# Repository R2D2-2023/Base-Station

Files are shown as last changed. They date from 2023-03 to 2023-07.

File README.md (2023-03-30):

# Base-Station

We are the team base-station.

> Our focus is on the charging of the robot and also maintaining the robot, by charging it and maybe updating it in times.
>  - Charging will be done with a contact pad and an arm that moves these pads to connect to the robot.
>  - Updating will be done by the same action, the pads all have a different function
>        The functions are;
>      - Charging, by using a ground and power pad.
>      - Data transfer.
>      - Powering on the Raspberry Pi for data transfers.

To see the [scrumboard](https://github.com/orgs/R2D2-2023/projects/4) of our team

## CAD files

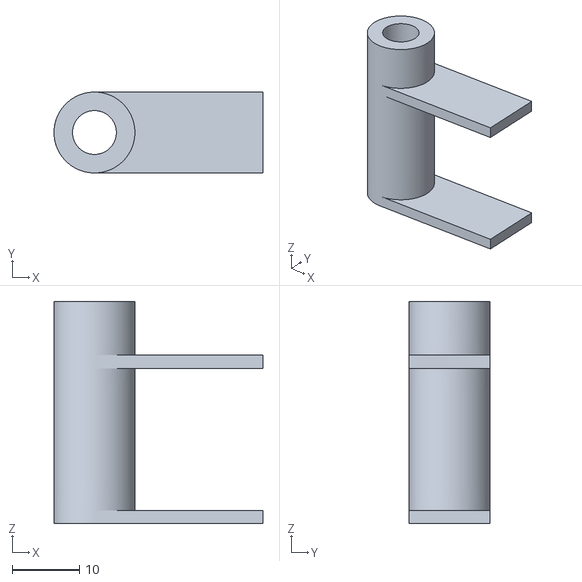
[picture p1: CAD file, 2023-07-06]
models/3d_models/LaserHouder.stl
31.0 x 12.0 x 33.0

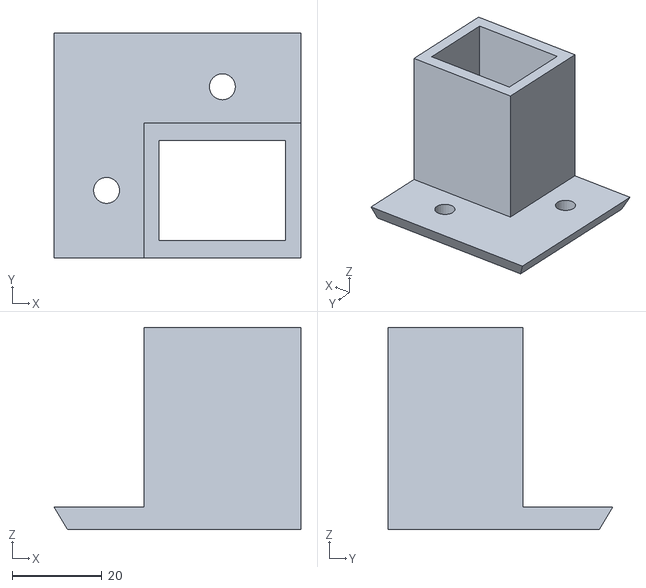
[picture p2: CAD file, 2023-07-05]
models/3d_models/holder_switch.stl
55.0 x 50.0 x 45.0

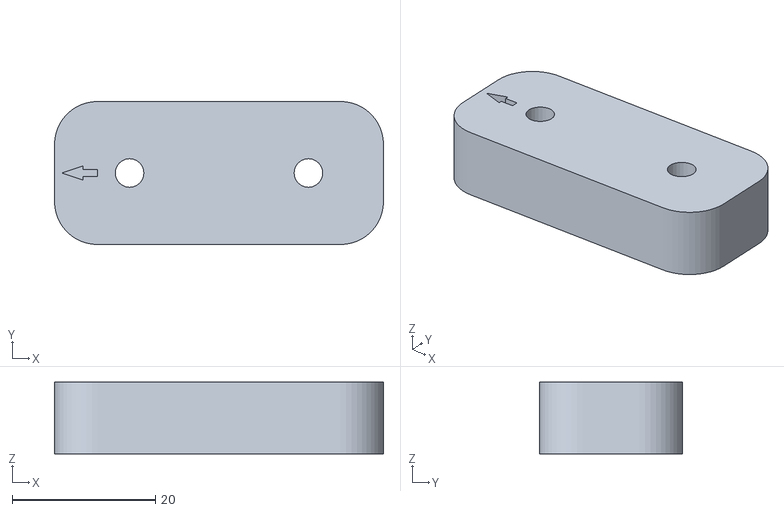
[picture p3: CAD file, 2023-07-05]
models/3d_models/connector_longside.stl
46.0 x 20.0 x 10.0

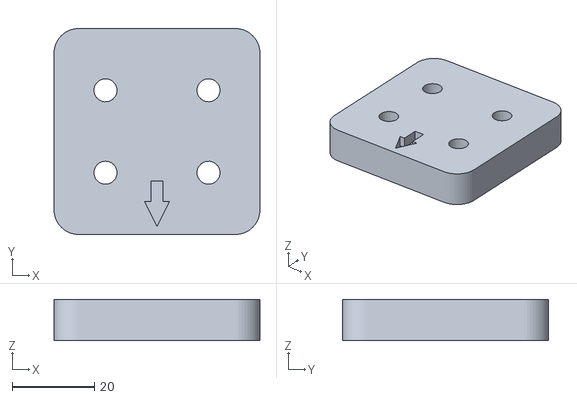
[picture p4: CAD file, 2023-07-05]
models/3d_models/middle_connector (1).stl
50.0 x 50.0 x 10.0

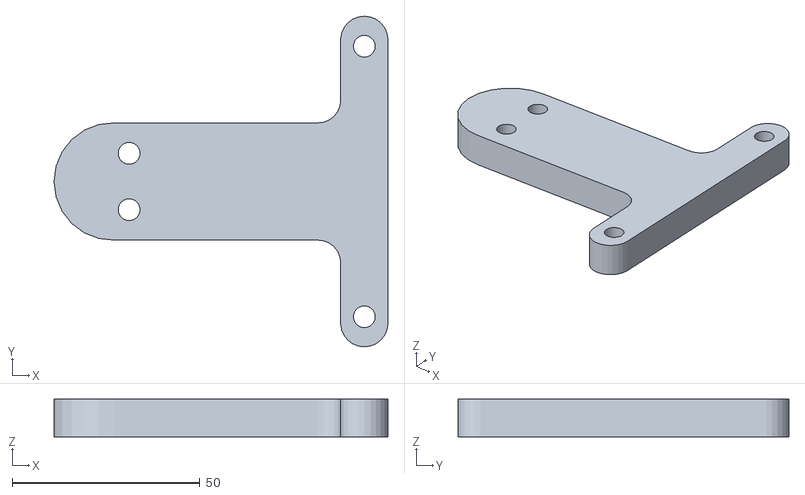
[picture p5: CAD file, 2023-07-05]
models/3d_models/T-connector (3).stl
88.9 x 88.0 x 10.0

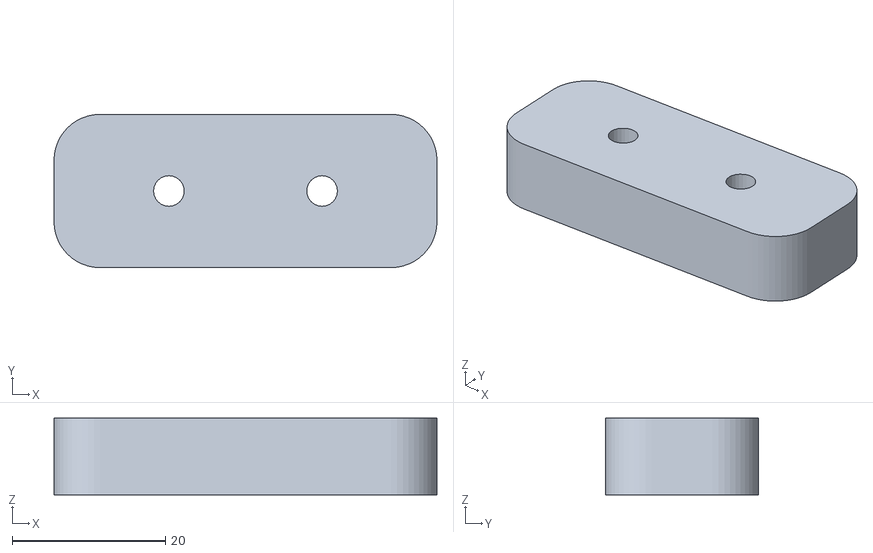
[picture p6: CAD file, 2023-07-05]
models/3d_models/connector_shortside (1).stl
50.0 x 20.0 x 10.0

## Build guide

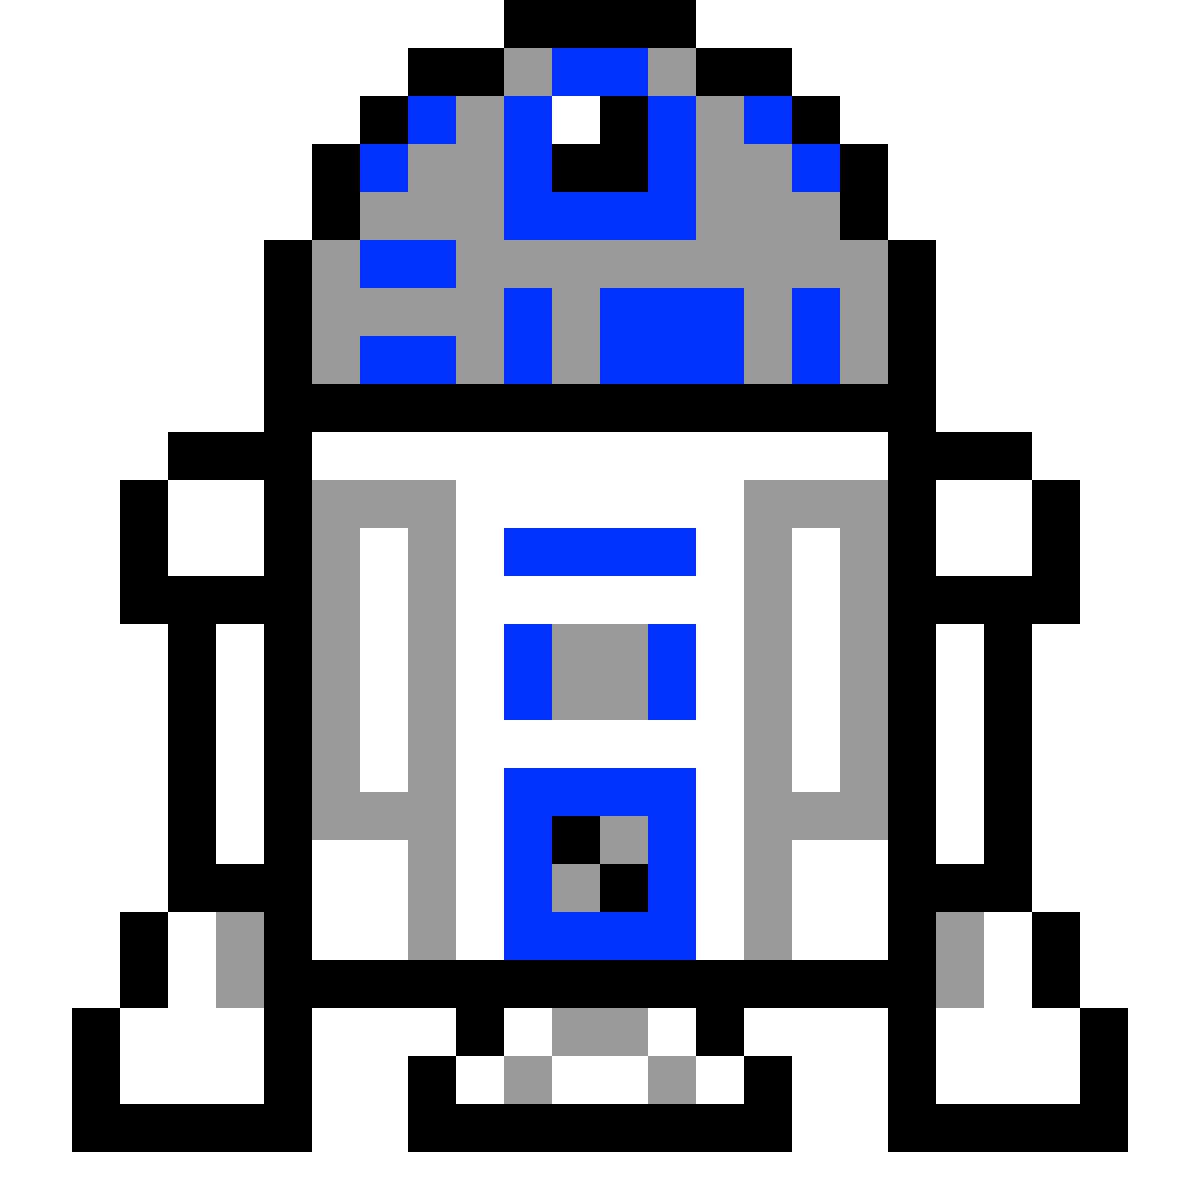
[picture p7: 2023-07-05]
Visualisation_software/cmake-build-debug-mingw/image.png

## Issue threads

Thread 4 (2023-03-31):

Loodcel op platform zetten

funrester1423, 2023-03-31:

funrester1423, 2023-04-11:
This sprint we built the mechanism out of wood and not of Lego parts, so overall it is sturdier than the original model.

We also decided to include additional beams for support, last sprint the single support beam was bent because of the weight of the pressure sensor.

funrester1423, 2023-06-12:
Done, mechanism is operational and attached to the project.

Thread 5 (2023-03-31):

Make platform for connective pads and pressure plate

funrester1423, 2023-03-31:
This is a part of the demo model.
- Making a prototype of the platform where we can place the pads and plate.

funrester1423, 2023-04-03:
Eventually the platform was made and functional, but it was not used in the prototype because the overall build was not strong enough for the weight of the pressure sensor (pressure plate) so we forwent attaching it to the first model.

funrester1423, 2023-04-11:
This has been pushed back to the previous and current sprint.

There were some changes in the build/materials also overall dimensions because of compromises with the other teams.
With the new model it should be stable compared to the older versions, we added more support beams to keep the platform more stable than it was.

funrester1423, 2023-06-12:
Issue has been moved to issue "Project".
All equivalent issues will be moved there.

Closed 2023-06-12.

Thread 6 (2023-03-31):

3D model

funrester1423, 2023-03-31:
- Making a model for the arm in SketchUp.
* This will be used to make a prototype of the arm.

funrester1423, 2023-06-12:
Issue has been moved to issue "Project".
All equivalent issues will be moved there.

Closed 2023-06-12.

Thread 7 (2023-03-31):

Apply Hall sensor

funrester1423, 2023-03-31:
Check if the arm doesn't apply too much pressure on the robot, to prevent our mechanism to break it.

funrester1423, 2023-04-03:
Functionality was fine last sprint, but it still has to be attached and we don't have the model that can support the weight of the platform.
This sprint we have to improve the existing design to make a more refined version of the arm.

funrester1423, 2023-04-11:
This sprint we have a more stable arm, with better materials and overall a better build. We added extra support for the top part of the mechanism, so the platform would stay secure and fixed to the mechanism, without it bending the mechanism to the heavier side.

This would've been a non-issue if the platform only had to hold the hallsensors and not the pressure block as well.

funrester1423, 2023-06-12:
Issue has been moved to issue "Project".
All equivalent issues will be moved there too.

Closed 2023-06-12.

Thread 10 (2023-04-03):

Demo arm

funrester1423, 2023-04-03:
Put the things from proof of concept into a working demo, to be shown to the other teams.

- An arm mechanism, that can extend itself when robot is in proximity.
- The sensors to know proximity of the robot.

funrester1423, 2023-04-03:
In the proof of concept we also had the pressure pads, these were not yet implemented in the full demo.
The pad itself was too heavy to be used with the current model, where the overall base of it is just too weak for a weight that would extend itself away from the base.
Though it is functional, it just could not be applied to the mechanism.

Closed 2023-04-03.

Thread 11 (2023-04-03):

Batterij research

funrester1423, 2023-04-03:
- Which battery will be used.
- How to charge said battery.
- How can we charge it safely.
- Estimation how long it would take to charge the battery.

funrester1423, 2023-04-04:
B-25C-3300-3S1P = The battery that will be used
- Charging methods that we could think of are.
- - Using a power outlet
- - Using a USB connection
- - Using coils
- - Using metal pads to replace cables.

funrester1423, 2023-06-05:
Only the coils have to be checked, but the other 3 methods have been tested.
- Overall the charging took a while.
- There isn't a very noticable difference in charging speed for all of them, which is probably based on the power that we can deliver.

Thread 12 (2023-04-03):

Parts list

funrester1423, 2023-04-03:
Parts needed for the mechanism

- 3144E Holzer hall sensor
- HX711 load cell 1kg
- 5V DC gear motor (unnamed/general)
- L9110S H-Bridge
- Wooden parts for mechanism and for ramp
- Wooden parts for the platform

funrester1423, 2023-06-05:
Ramp was removed because of clashes with the mobile platforms model, it can't go up ramps.

Added items to the list for testing charge speeds:
- Coils
- Pads

funrester1423, 2023-06-12:
All parts and additional parts have been acquired.

Closed 2023-06-12.

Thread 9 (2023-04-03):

Demo model v2

funrester1423, 2023-04-03:
Making a second model, which is meant to be an improvement to our model from the previous sprint.
Focusing on making a more stable model, that would be able to carry their parts.

- Same parts as before, but increasing the durabilty of the material or improving the design, for stability.

funrester1423, 2023-06-12:
Issue has been moved to issue "Project".
All equivalent issues will be moved there.

Closed 2023-06-12.

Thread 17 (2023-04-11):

Battery management

funrester1423, 2023-04-11:
Making a system to check if the battery is full.

This might be a good addition predominantly for safety and longevity of the battery.
At least we should be able to know when the battery is full and not overload the battery.

funrester1423, 2023-06-12:
New plan:
- We will be making a display in the base station to display the battery level of the robot, this will be done in tandem with the backend, where they have the current battery reading of the robot during it's run.

funrester1423, 2023-06-26:
We only need access to the backend for their collection of data, so we could take the battery levels, that they should be getting from the robot as well.

funrester1423, 2023-06-27:
The battery management will be done with an animation of how full the battery is at the front of the charging station.
But we heard that the mobiel platform are going to add an additional battery to their robot so at least it would have enough power to run every hardware and actually move faster than a couple meters per second.

funrester1423, 2023-06-30:
The status will be sent by MQTT, which would provide connections between the two raspberry pi's, one that can read the battery levels and the other pi will be used to control the LED-matrix

Closed 2023-07-07.

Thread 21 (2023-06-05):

Research

funrester1423, 2023-06-05:
- Prep charging methods (Kyrill)
- Weighing down wires (Erik)
- Check safety and efficiency (Jasper + Kalil)
   - Start the research (All)
   - Proces results (All)

funrester1423, 2023-06-12:
Coils definitely will not be the choice that we will be going with, because of it's severe inefficiency.
Comparatively to the other options, the coils charges way too slow to be functional.

funrester1423, 2023-06-19:
Research paper has been finished and submitted.

- For the week; a presentation has to be made.

Closed 2023-06-20.

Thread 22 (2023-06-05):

Project (Charging station)

funrester1423, 2023-06-05:
For the project, basically for the product we still have to do the following things:

- Build frame for the docking station.
- Finish electronics for the docking station.
- The pad model must revised, because of the new model of the product.
- Looking for LED matrix and testing it.
- Connection with the database from backend.

funrester1423, 2023-06-27:
Most of parts are working independently, just needs to fix some small bugs with sensors.

- The extracurricular thing was revised from last weeks product, which we already coded, but apparently the library does not support the configuration that we had made.

funrester1423, 2023-07-03:
Extracurricular items are now finished, we only have a slight drawback, the raspberry Pi that controls the pads was corrupted, so we have to remake the Pi, which shouldn't take too long and would be done for tomorrow, so we can have a final check if everything works and error free, to the extent that it is functional enough to do what we need it to do.

The sensors are all working as intended, we have to just place the plate and also reinstall the second Pi.

funrester1423, 2023-07-07:
Finished the product, has a bit of a delay till startup, but for the most part is fully functional, might have some test cases where it doesn't, but we couldn't get to that before the deadline of the project.

Closed 2023-07-07.

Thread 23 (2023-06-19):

Mainframe

funrester1423, 2023-06-19:
Piecing together the charging box:

- Frame of the box
- Completing mechanism.

funrester1423, 2023-06-26:
Frame might need some reinforcements, to keep the lasers on their position.

funrester1423, 2023-06-27:
The motor is slowly but surely wrecking our frame, the overall pressure caused by the 2 motors is too high for the thin wooden frame we made for the mechanism, at least the overall box, where the mechanism will be situated, has a much stronger and thicker frame than the mechanism.

funrester1423, 2023-06-30:
Added small art to replace the empty space left from the planned panel on the top and to block the mess on the top.

funrester1423, 2023-07-03:
We did our utmost to make it into a presentable frame, but in my honest opinion in needs some work, but getting it to look better than what we have right now would need more time to hide some wiring monstrosities.

Hopefully none of thge wires would be moved till the show and tell, but once one of the wires are not in their position it might not work, we will make a picture of how it should look like and how things are connected.

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

Closed 2023-07-07.

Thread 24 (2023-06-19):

Visualisation software

funrester1423, 2023-06-19:
Controlling the LED-matrix for the dashboard and also a dedicated LED-matrix for pixel art.

- Pixel art is optional to be fully functional, so if it's not working perfectly, this shouldn't matter.
- Dashboard function should be for battery information, info that can be pulled from back-end.

funrester1423, 2023-07-03:
The Visualisation software has been made and are both functional, they are being controlled by a seperate Pi, because the connectors for the LED-matrixes take up all the GPIO pins.

A problem surfaced today (3/7), where the Raspberry Pi that controls the matrixes got corrupted, so Daniel was sent out to flash and reinstall the OS, this took a while, which where we found out that the problem is not the Pi, so that stay, but the SD-card that we were using, just suddenly gave up, so that has been changed and now only makefiles have to be remade for the new SD-card.

Closed 2023-06-20.

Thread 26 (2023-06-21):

Combine all parts

funrester1423, 2023-06-21:
Minecrafting, building block

funrester1423, 2023-06-27:
Parts are for the most part functional again, for this week (26/6) only the LED-matrix had to revised again before implementing into the charging station. Might need to think of a better fix for the stability of the lasers, but as long as the charging station frame doesn't move a signifcant amount, it should be fine.

funrester1423, 2023-07-03:
All parts are now functional and have been tested, the thing that we have to finish is just to add MQTT to the raspberries, this should allow us to send small data, in our case a string, to the other Pi.

Closed 2023-07-07.

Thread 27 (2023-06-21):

Sensors

funrester1423, 2023-06-21:
Tune sensors to where it has to be.

funrester1423, 2023-06-26:
Lasers have been set up, but might need to do something about the janky solution that we have right now, might not.

funrester1423, 2023-06-27:
- Leadcels weren't functioning properly, found out it was in the wrong ports, so that was fixed fast enough.
- Lasers are now aimed properly, but as long as the charging station frame moves too much, it might move the laser away from the receiver.
- Halsensors should be working properly, it at least shows when it is being activated, only the software needs an update, because the function of the sensors have been changed slightly.

funrester1423, 2023-07-03:
We had a couple problems with the sensors after turning the mechanism on today, this bug has been fixed by Erik and Kalil.

Closed 2023-06-30.

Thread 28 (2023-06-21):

Connection with back-end

funrester1423, 2023-06-21:
Get data for the dashboard, this includes voltage, possibly also the current position of the robot.

funrester1423, 2023-06-30:
The dashboard has been removed from our project, this has been replaced by just the battery level indicator.

Closed 2023-07-03.

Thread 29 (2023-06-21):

LED-Matrix Dashboard

funrester1423, 2023-06-21:
Dashboard specific panels / code.

funrester1423, 2023-06-27:
LED-matrix doesn't work as intended, so one of the matrix sets will have to be removed and exchanged with a different matrix.

- The original setup of one set of matrixes; 32x48 and 32x32, did not work as intended, the pixels aren't being adressed properly because of the specific configuration that we are running, the library only support a configuration with either same pixel height or width, but can't address this current config.
- The fix to this is to to remove the 32x32 setup and just swap it with an extra 16x32, which should work.

funrester1423, 2023-06-29:
Doing some final debugging, but it should be functional by today.

funrester1423, 2023-06-30:
Dashboard has been removed from the project, has been replaced by a battery indicator, the panel had to be shrunk to a single 16x32 panel, so a Dashboard doesn't seem possible to show on such a small panel.

- Battery level indicator has been finished, just needs to be connected to the battery reader on the robot, back-end or mobiel-platform.

funrester1423, 2023-07-03:
There was a problem with the Raspberry Pi that we had, after a couple hours of flashing SD-cards and re-installing Raspberian later we found out it was a problem with the SD-card and not the Pi.

This was done by Daniel and David for the most part. It took a while, but we finally found the problem and it is now fixed.

Only right now we are left with the problem of rebuilding the flashed drive of the Pi.
Things like makefiles and the clone of the repositories.

Closed 2023-07-07.

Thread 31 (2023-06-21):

Get parts to finish the box

funrester1423, 2023-06-21:
Have to get parts to finish the box, primarily new wooden boards, that will be used to close the box and extra plates for maybe mistakes and also for the robot and our charging pads.

funrester1423, 2023-06-27:
The wooden boards have been acquired together with the copper tape, so all the materials should be in inventory, if there are more purchases needed that will be added later and the issue will be reopened.

Closed 2023-06-27.

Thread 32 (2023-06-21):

Print parts for the panels

funrester1423, 2023-06-21:
3D print parts necessary to connect panels to each other.

funrester1423, 2023-06-22:
Position of holes for the parts are not symmetrical to each panel, so position of the panels have impact to the the form of the parts, so now we are making new parts that corresponds with the panel positioning.

funrester1423, 2023-06-27:
3D printed parts have been finished and added to the the mechanism, this issue should be done, unless we have to make final revisions for stability, which we think would be very unlikely.

funrester1423, 2023-07-03:
All parts should be finished, there should be no more additions for the last 2 days, because this wouldn't be doable in less that 2 days time.

Closed 2023-06-27.

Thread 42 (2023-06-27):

Charging panels

funrester1423, 2023-06-27:
The panels are made of wood and the pads will be swapped  out for copper tape, instead of aluminium pads, that's because copper is a way better conductor, also a tape is easier to apply than cutting the pads then pasting them on the pads.

funrester1423, 2023-06-27:
The original plan last week was to make two of these plates; one for base-station and one for mobiel-platform

* This was changed slightly, because the division of space on the mobiel-platform was changed, because of changes in hardware.
 - So we have to make new cut outs and also do the platings again.
 - The comment above is an extention of this comment, which missed the additional information that the original idea was already made, but after hearing that a new one had to be made, we thought of things to improve it, including using copper tape instead of aluminium pads.

funrester1423, 2023-06-27:
We have printed the secondary plate needed for mobiel platform, we only need to apply the copper tape to it, then we have to test if it fit and check how they are going to do the connectors for the 2 batterycells that they are going to use.

- The mobiel platform has to check how to connect the two battery, parallel or in sequence, dependant on how they want to do the connection we have to change how we charge the robot.

funrester1423, 2023-06-29:
Both plates are finished, only need to be added to the mechanism and to the mobiel platform.

funrester1423, 2023-07-03:
The cables only need to be soldered together and connected to the mainframe.
- We still have to discuss how we are going to arrange the pads, but the mobiel platform still needs to finish their robot, this might not happen.

Closed 2023-06-29.

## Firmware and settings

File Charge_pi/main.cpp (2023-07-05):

#include <wiringPi.h>
#include <stdio.h>
#include <stdlib.h>
#include <iostream>
#include "HX711.h"
#include <wiringSerial.h>
#include <sstream>
#include <string>

#include <cstdlib>
#include <thread>	// For sleep
#include <atomic>
#include <chrono>
#include <cstring>
#include "mqtt/async_client.h"


const std::string DFLT_SERVER_ADDRESS { "tcp://145.89.224.225:1883" };

const std::string TOPIC { "BasedStation" };
const int QOS = 1;

const char* PAYLOADS = {"charging"};
const char* PAYLOADS2 = {"done"};

const auto TIMEOUT = std::chrono::seconds(10);

int clock_pin = 9;
int data_pin1 = 2;
int data_pin2 = 3;

int light_sensor1 = 25;
int light_sensor2 = 24;

int hall_sensor_1 = 4;
int hall_sensor_2 = 5;

int motor_pin_1 = 21;
int motor_pin_2 = 22;
int relais_pin = 23;


HX711 scale_1(clock_pin, data_pin1);
HX711 scale_2(clock_pin, data_pin2);

int state = 0; //0 = idle, 1 = robot entering, 2 = moving down, 3 = charging, 4 = going up

char serial_port[12];
std::string serial_text; // max length for serial string.


void setup(){
	wiringPiSetup();
   	
	serialOpen("/dev/ttyACM2", 115200);
	serialFlush(4);

    scale_1.start(1058);// this works to calabrate the scale
    scale_2.start(-185);//  ^^
    pinMode(light_sensor1, INPUT);
	pinMode(light_sensor2, INPUT);
	pinMode(hall_sensor_1, INPUT);
	pinMode(hall_sensor_2, INPUT);
	pinMode(motor_pin_1, OUTPUT);
	pinMode(motor_pin_2, OUTPUT);
	pinMode(relais_pin, OUTPUT);
	
	digitalWrite(motor_pin_1, HIGH);
	digitalWrite(motor_pin_2, HIGH);
	digitalWrite(relais_pin, LOW);
	pinMode(relais_pin, INPUT);


	std::cout << "Starting in 3" << std::endl;
	delay(1000);
	std::cout << "Starting in 2" << std::endl;
	delay(1000);
	std::cout << "Starting in 1" << std::endl;
	delay(1000);
}

int main(int argc, char* argv[]) {
	
	setup();
	int timer = millis();
	while (1){
		switch(state){
				case 0:{
					if (digitalRead(light_sensor1)){
						//robot started entering
						std::cout << "Sensor1\n";
						state = 1;
					}
				break;}
				case 1:{
					timer = millis();
					if(millis() - timer >= 5000){
						state = 0;
					}
					if (digitalRead(light_sensor2)){
						//robot has entered
						std::cout << "Sensor2\n";
						digitalWrite(motor_pin_1, HIGH);
						digitalWrite(motor_pin_2, LOW);
						state = 2;
					}
				break;}
				case 2:{
					std::cout << "Robot will move down.\n";
					if(!digitalRead(hall_sensor_2)){
						std::cout << "FULLY EXTENDED RETRACTING..." << std::endl;
						digitalWrite(motor_pin_1, LOW);
						digitalWrite(motor_pin_2, HIGH);
						state = 4;
					}
					int grams1 = scale_1.getAvg(2);
					int grams2 = scale_2.getAvg(2);
					std::cout << "avg1:" << grams1 << "\t";
					std::cout << "avg2:" << grams2 << std::endl;
					if (grams1 >= 4000 && grams2 <= 2000){
						digitalWrite(motor_pin_1, LOW);
						digitalWrite(motor_pin_2, LOW);
						std::cout << "Opladen + schrijven" << std::endl;
						delay(1000);
						system("/home/pi/BaseStationBashSkrippie/uploadArduino");
						
						delay(5000);
						state = 3;
					}
				break;}
				case 3:{
					
					std::string address = (argc > 1) ? std::string(argv[1]) : DFLT_SERVER_ADDRESS;
					std::cout << "Initializing for server '" << address << "'..." << std::endl;
					mqtt::async_client cli(address, "");

					std::cout << "  ...OK" << std::endl;

					try {
						std::cout << "\nConnecting..." << std::endl;
						cli.connect()->wait();
						std::cout << "  ...OK" << std::endl;

						std::cout << "\nPublishing messages..." << std::endl;

						mqtt::topic top(cli, TOPIC, QOS);
						mqtt::token_ptr tok;
	
		
						tok = top.publish(PAYLOADS);
		
						tok->wait();	// Just wait for the last one to complete.
						std::cout << "OK" << std::endl;

						// Disconnect
						std::cout << "\nDisconnecting..." << std::endl;
						cli.disconnect()->wait();
						std::cout << "  ...OK" << std::endl;
					}
					catch (const mqtt::exception& exc) {
						std::cerr << exc << std::endl;
					}
					pinMode(relais_pin, OUTPUT);
					digitalWrite(relais_pin, HIGH);

					std::cout<<"charging\n";
					if(serialDataAvail(4)){
						std::cout << "Data available\n";
						for (int i = 0; i <= 3; i++){
							serial_text[i] = serialGetchar(4);
						}
						std::cout << serial_text.c_str() << std::endl; 	
					}
								
					if(serial_text[0] == 'h' &&serial_text[1] == 'e' && serial_text[2] == 'y'){
						//charging done, arm starts going up. 
						try {
							std::cout << "\nConnecting..." << std::endl;
							cli.connect()->wait();
							std::cout << "  ...OK" << std::endl;

							std::cout << "\nPublishing messages..." << std::endl;	

							mqtt::topic top(cli, TOPIC, QOS);
							mqtt::token_ptr tok;
	
							tok = top.publish(PAYLOADS2);
		
							tok->wait();	// Just wait for the last one to complete.
							std::cout << "OK" << std::endl;

							// Disconnect
							std::cout << "\nDisconnecting..." << std::endl;
							cli.disconnect()->wait();
							std::cout << "  ...OK" << std::endl;
						}
						catch (const mqtt::exception& exc) {
							std::cerr << exc << std::endl;
						}
						
						std::cout << "stop charging received\n";
						digitalWrite(motor_pin_1, LOW);
						digitalWrite(motor_pin_2, HIGH);
						digitalWrite(relais_pin, LOW);
						pinMode(relais_pin, INPUT);
						state = 4;
					}

				break;}
				case 4:{
					if (!digitalRead(hall_sensor_1)){
						// arm is full retracted
						std::cout << "retracted" << std::endl;			
						digitalWrite(motor_pin_1, LOW);
						digitalWrite(motor_pin_2, LOW);
						state = 0;
					}
				break;}
				
		}
		delay(500);
	}
}

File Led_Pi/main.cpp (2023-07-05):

#include "/home/pi/rpi-rgb-led-matrix/include/led-matrix.h"

#include <unistd.h>
#include <math.h>
#include <stdio.h>
#include <signal.h>
#include <mqtt/async_client.h>

#include <iostream>
#include <math.h>
#include <fstream>
#include <sstream>
#include <string>

#include <sys/types.h>
#include <sys/stat.h>
#include <ctime>
#include <chrono>


#include "MQTTClient.h"
#include <cstdlib>
#include <cstring>
#include <cctype>
#include <thread>
#include "mqtt/async_client.h"

#include "Matrix.hpp"


const std::string SERVER_ADDRESS("tcp://145.89.224.225:1883");
const std::string TOPIC("BasedStation");

const int       QOS = 1;
const int       N_RETRY_ATTEMPTS = 5;
bool charging = false;

/////////////////////////////////////////////////////////////////////////////

// Callbacks for the success or failures of requested actions.
// This could be used to initiate further action, but here we just log the
// results to the console.
class action_listener : public virtual mqtt::iaction_listener
{
        std::string name_;

        void on_failure(const mqtt::token& tok) override {
                std::cout << name_ << " failure";
                if (tok.get_message_id() != 0)
                        std::cout << " for token: [" << tok.get_message_id() << "]" << std::endl;
                std::cout << std::endl;
        }

        void on_success(const mqtt::token& tok) override {
                std::cout << name_ << " success";
                if (tok.get_message_id() != 0)
                        std::cout << " for token: [" << tok.get_message_id() << "]" << std::endl;
                auto top = tok.get_topics();
                if (top && !top->empty())
                        std::cout << "\ttoken topic: '" << (*top)[0] << "', ..." << std::endl;
                std::cout << std::endl;
        }

public:
        action_listener(const std::string& name) : name_(name) {}
};

/////////////////////////////////////////////////////////////////////////////

/**
 * Local callback & listener class for use with the client connection.
 * This is primarily intended to receive messages, but it will also monitor
 * the connection to the broker. If the connection is lost, it will attempt
 * to restore the connection and re-subscribe to the topic.
 */
class callback : public virtual mqtt::callback,
                                        public virtual mqtt::iaction_listener

{
        // Counter for the number of connection retries
        int nretry_;
        // The MQTT client
        mqtt::async_client& cli_;
        // An action listener to display the result of actions.
        action_listener subListener_;

        // This deomonstrates manually reconnecting to the broker by calling
        // connect() again. This is a possibility for an application that keeps
        // a copy of it's original connect_options, or if the app wants to
        // reconnect with different options.
        // Another way this can be done manually, if using the same options, is
        // to just call the async_client::reconnect() method.
        void reconnect() {
                std::this_thread::sleep_for(std::chrono::milliseconds(2500));
                try {
                        cli_.connect(nullptr, *this);
                }
                catch (const mqtt::exception& exc) {
                        std::cerr << "Error: " << exc.what() << std::endl;
                        exit(1);
                }
        }

        // Re-connection failure
        void on_failure(const mqtt::token& tok) override {
                std::cout << "Connection attempt failed" << std::endl;
                if (++nretry_ > N_RETRY_ATTEMPTS)
                        exit(1);
                reconnect();
        }

        // (Re)connection success
        // Either this or connected() can be used for callbacks.
        void on_success(const mqtt::token& tok) override {}

        // (Re)connection success
        void connected(const std::string& cause) override {
                std::cout << "\nConnection success" << std::endl;
                std::cout << "\nSubscribing to topic '" << TOPIC << "'\n"
                        << " using QoS" << QOS << "\n"
                        << "\nPress Q<Enter> to quit\n" << std::endl;

                cli_.subscribe(TOPIC, QOS, nullptr, subListener_);
        }

        // Callback for when the connection is lost.
        // This will initiate the attempt to manually reconnect.
        void connection_lost(const std::string& cause) override {
                std::cout << "\nConnection lost" << std::endl;
                if (!cause.empty())
                        std::cout << "\tcause: " << cause << std::endl;

                std::cout << "Reconnecting..." << std::endl;
                nretry_ = 0;
                reconnect();
        }
		
        // Callback for when a message arrives.
        void message_arrived(mqtt::const_message_ptr msg) override {
                std::cout << "Message arrived" << std::endl;
                std::cout << "\ttopic: '" << msg->get_topic() << "'" << std::endl;
                std::cout << "\tpayload: '" << msg->to_string() << "'\n" << std::endl;
                std::cout << "test 3" << std::endl;
        std::string status = msg->to_string();
        if(status == "charging"){
            charging = true;
        }
        else if(status == "done"){
            charging = false;
        }
        }

        void delivery_complete(mqtt::delivery_token_ptr token) override {}

public:
        callback(mqtt::async_client& cli)
                                : nretry_(0), cli_(cli), subListener_("Subscription") {}
};

/////////////////////////////////////////////////////////////////////////////


//ToDo:
//iets met de map functie klopt niet
//soms kunnen de files niet gevonden worden

volatile bool interrupt_received = false;
static void InterruptHandler(int signo) {
  interrupt_received = true;
}

//simple map function to get variable in 1 range to other range.
long map(float x, float in_min, float in_max, float out_min, float out_max){
    return(x - in_min) * (out_max - out_min) / (in_max - in_min) + out_min;
}

//get the voltage of the robot fromt he database.
std::string readFromDB(){
	system("/usr/bin/python3.9 /home/pi/Base-Station/dataBase.py");
	usleep(200000); //wait for python script to be done.
	std::string bestands_naam = "/home/pi/Base-Station/voltage.txt";
	std::ifstream voltage(bestands_naam);
	if(!voltage.is_open()){
			return "could not open file";
	}
			std::string line;
	std::getline(voltage, line);
	return line;
}
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

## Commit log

2023-03-30 Create sketch_mar27b.ino
    Als de hall sensor een magnetish veld ziet stopt de motor met draaien.
2023-03-31 Updated the sketch
    Als de robot binnen komt begint de arm naar boven te draaien. Mocht de robot tussen tijds weg gaan stopt de arm.
    Met de huidige code zal de arm op en neer bewegen.
2023-03-31 LoadCell
    Jasper's loadcel is hier ook in verwerkt. Nu als de robot er is begint hij te draaien, indien die binnen het veld van hallSensor1 valt.
2023-03-31 Nog een update
    Er stonden een paar foutjes in. die zijn er nu uit gewerkt. daarnaast wat printlns voor debugging.
2023-04-04 WiringPi HX711 (loadcell) library
    Dit is een loadcell 1kg library voor C++ op de raspberry pi met gebruik van de WiringPi library.
2023-04-14 raspberry code files
2023-04-14 added lasercut files
2023-04-14 added 3d models
    [base_station (1).stl, base_station (2).stl, base_station.stl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]
2023-06-15 Start van het visualiseren
    Jasper en ik zijn begonnen met een visualisatie aan te maken voor de ledmatixen.
2023-06-15 SMoll update
    Update to try fix some undiffined problem
    [main.cpp]
2023-06-16 Added a color wheel
    Added a interface to choose a color
2023-06-16 Painting.cpp + Painting.h added
    Added a class for painting support, several bugs like crashing and not painting not fixed yet. Matrix and Led class works for now.
    [main.cpp]
2023-06-19 Werkende versie 1.0
    Er zijn 3 matrixen die op het teken scherm worden weergegeven. Bij sluiten van het programma, worden er 3 bestanden aangemaakt met de juiste RGB waardes om gebruikt te worden door de led matrixes.
2023-06-20 Visueel programma kwartslag gedraaid
    Visueel programma is nu een kwartslag gedraaid zodat we 3 matrixes horizontaal kunnen tekenen i.p.v verticaal.
2023-06-21 Added 2d design files for lasercutter
2023-06-21 added 3d designs
    [T-connector (2).stl, charge_arm.stl, middle_connector.stl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]
2023-06-22 Upload python code to retrieve voltage
    Python code to retrieve voltage from backend. Logins are stored in a hidden file called "login.hidden" to protect the database logins.
2023-06-23 Added functionality
    Added functionality to show a background image. Added a function to make a led matrix file from image.
    Trying to add the jsoncpp and curl library to immediately upload to dropbox. Not working yet.
    [main.cpp]
2023-06-26 a new version of the full code
    it now has 2 working loadcells and the lightsensors have been added. Only the chargeboard should be added.
2023-06-27 made the code according to the flowchart
    We changed the code to be in sync with the flowchart we made. also found a bug where the arm won't go down because hallsensor1 keeps detecting it.
    [test.cpp]
2023-06-27 Basestation full code
    In the previous patch we made a small mistake. This code is tested and does what is supposted to. Only needs to add charging.
    [test.cpp]
2023-06-30 Battery status indicator animation done.
2023-06-30 updated battery indicator
    battery animation now flashes if voltage is way too high or low. database is now queried only once a minute. general cleanup of code.
    [main.cpp]
2023-07-03 Update main.cpp
    Manual merge of files because Github didn't recognise the changes
    [main.cpp]
2023-07-03 Added models
    [T-connector (3).stl, connector_longside.stl, connector_shortside (1).stl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]
2023-07-03 Restructured files
    [T-connector (2).stl, charge_arm.stl, middle_connector.stl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]
2023-07-03 Add files via upload
    Fixed crash when mouse was outside border window.
    Added small tutorial for image.png.
    Removed blue dot top-left.
    [main.cpp]
2023-07-04 Added mqtt
    added a mqtt part to sent a signal from the charingPi to the matrixPi so the martixPi knows it is charging.
    CO-AUTHORED-BY = DavHul <david.hulsebosch@student.hu.nl>
2023-07-04 New mqtt command added
    added a mqtt part to sent a signal from the charingPi to the matrixPi so the martixPi knows it is charging. and when its done.
    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
2023-07-04 added a relais and relays pins
    added the planned relays for charging so it doesn't constantly putout 12 volt on the strips.
    [main.cpp]
